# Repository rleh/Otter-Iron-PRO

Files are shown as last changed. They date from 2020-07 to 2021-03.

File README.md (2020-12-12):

# Otter-Iron-PRO

USB-PD soldering station for JBC C245 handles based on the [Otter-Iron](https://github.com/Jan--Henrik/Otter-Iron). More coming soon :)

 - v1.0 tested, works but not great
 - v1.1 untested, wont be tested
 - v2.0 tested, works great! (update: It seems to draw too much current, needs fix)

## Firmware

 - Requests and configures for USB-PD profile of 30 W or 80 W (allows variable).
 - Current limit automatically set based on PD profile available.
 - Profiles can be changed in firmware and enumerated profile will show at start up.
 - Prevents MOSFET driving if no/incompatiable USB-PD profile is advertised; allows setup/flashing with standard USB port.




## v1.0





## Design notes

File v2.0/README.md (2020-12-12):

[https://twitter.com/JanHenrikH/status/1255966040703541251](https://twitter.com/JanHenrikH/status/1255966040703541251)

[BOM](https://github.com/jeanthom/Otter-Iron-PRO-BOM)




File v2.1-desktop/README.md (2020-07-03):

# Otter-Iron-PRO v2.1-desktop

is variant of the _Otter-Iron-PRO v2.0_ designed for desktop-use.

Additional to/instead of USB-PD is can be supplied from any lab power supply with ?? to ?? V.
A cheap switch-mode mains power supply works as well, a stackable enclosure for a  _Meanwell RPS-???_ will be designed in the future.

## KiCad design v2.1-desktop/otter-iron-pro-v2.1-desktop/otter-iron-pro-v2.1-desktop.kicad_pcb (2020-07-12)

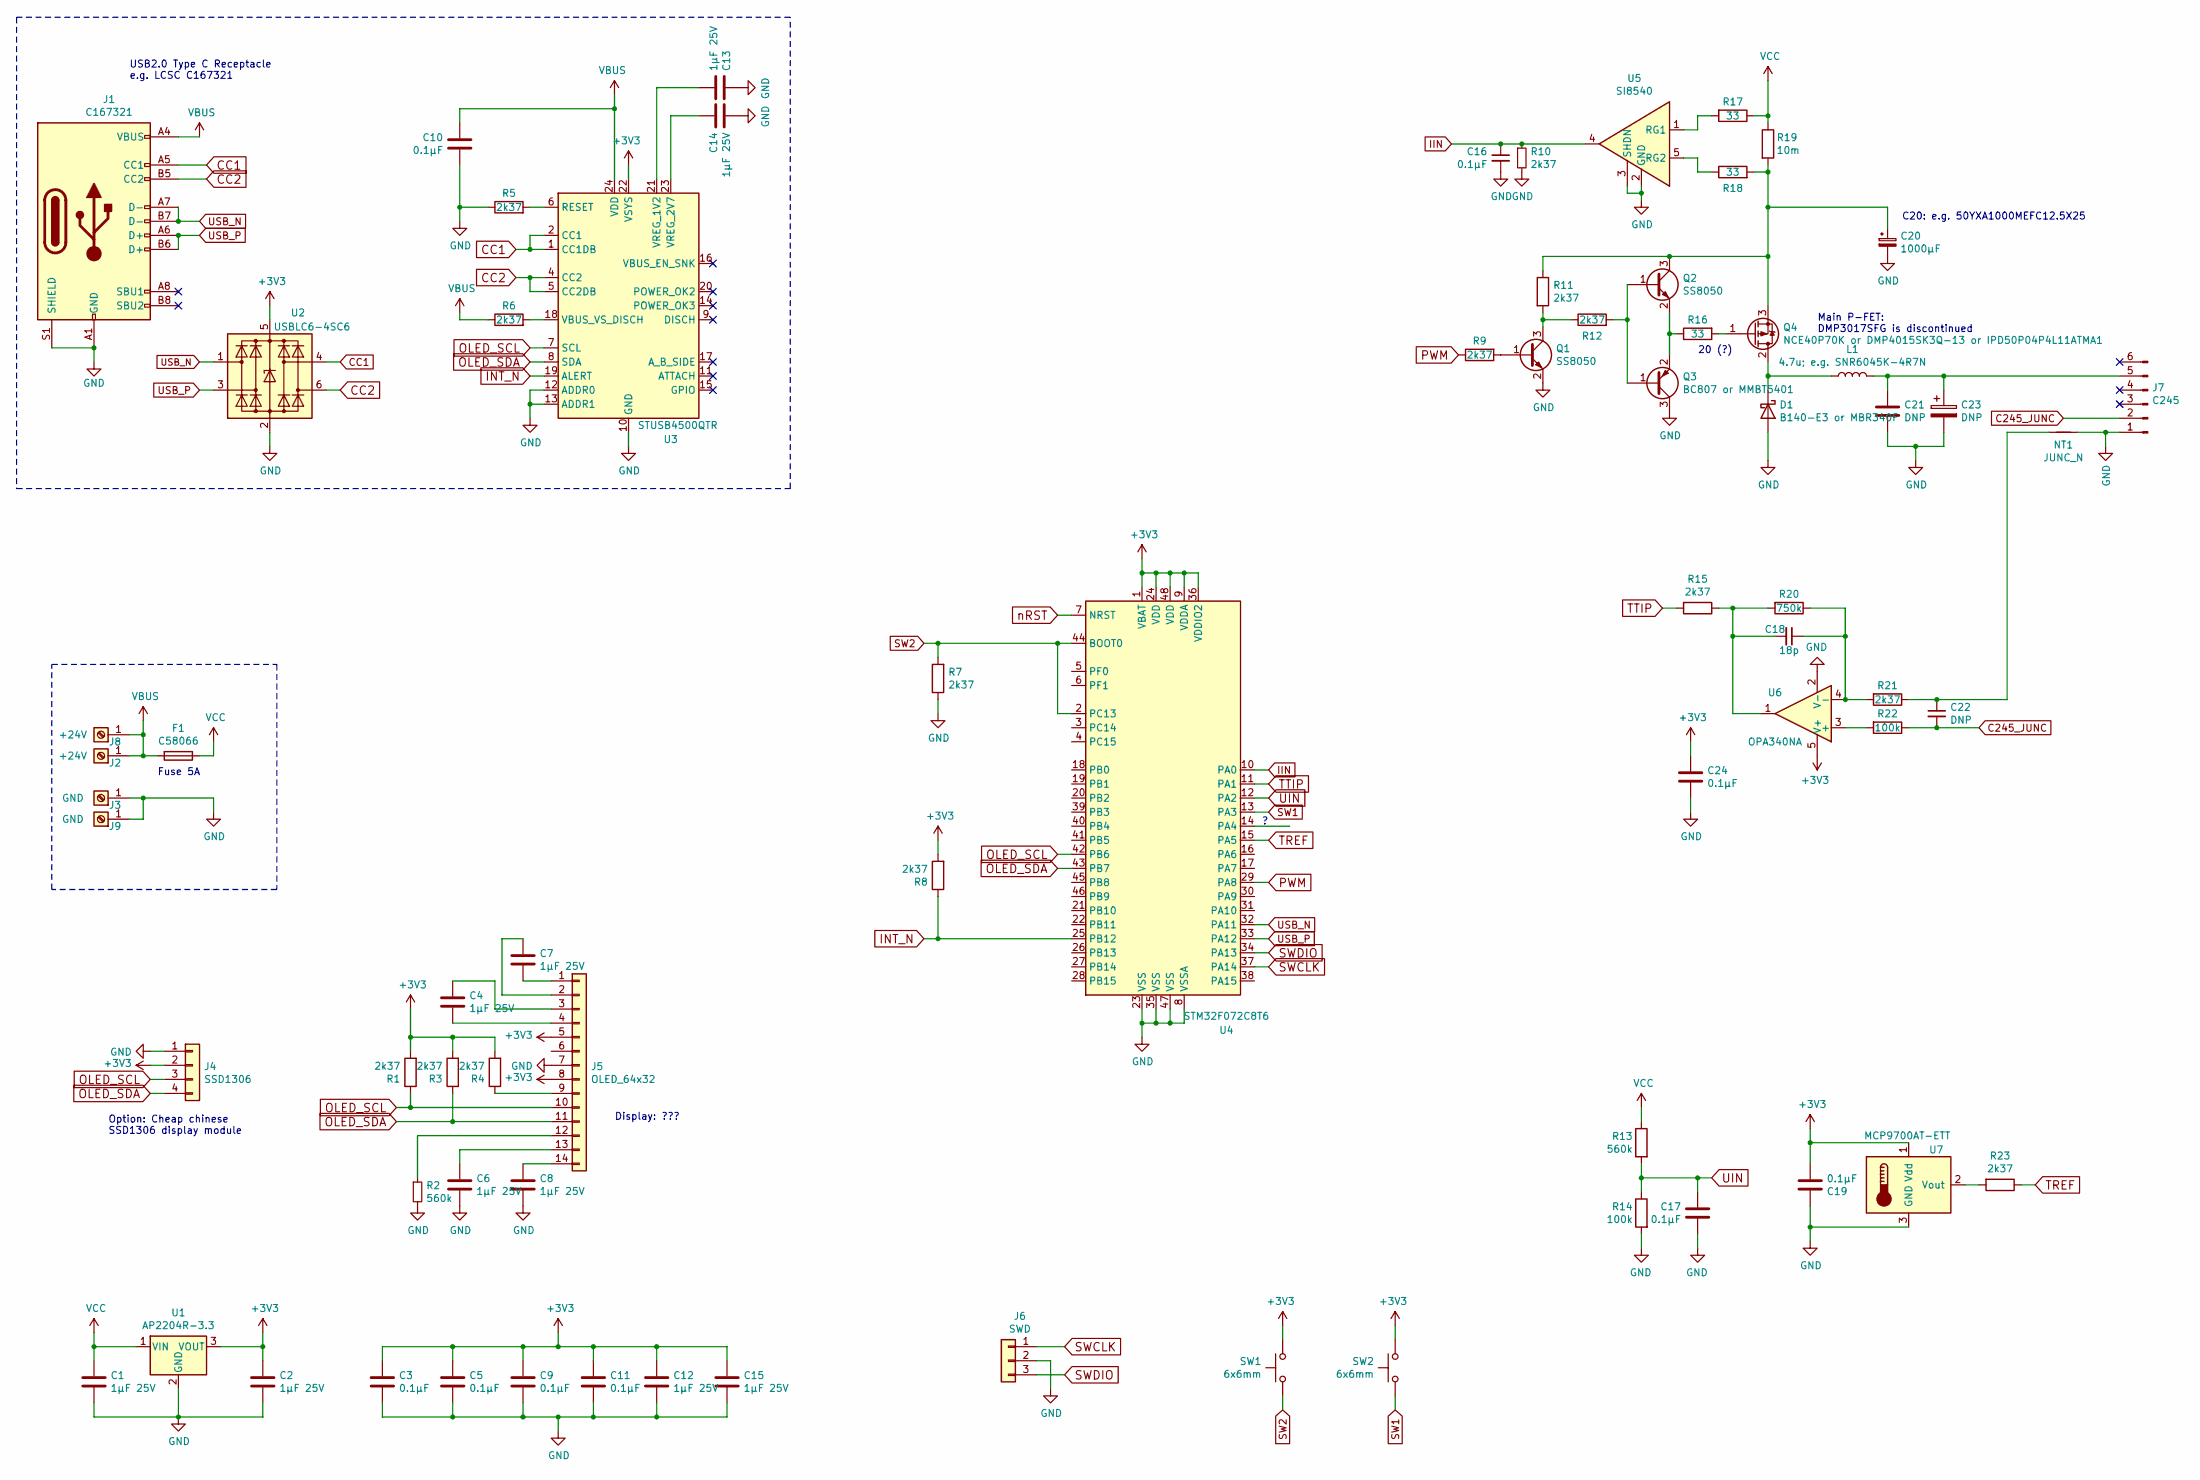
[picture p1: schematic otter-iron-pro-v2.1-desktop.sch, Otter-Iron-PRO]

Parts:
C1, C2, C4, C6, C7, C8, C12, C13, C14, C15: 1μF 25V; C_0603_1608Metric; LCSC C115388
C3, C5, C9, C10, C11, C16, C17, C19, C24: 0.1μF; C_0603_1608Metric; LCSC C30926
C18: 18p; C_0603_1608Metric; LCSC C126551
C20: 1000µF; CP_Radial_D12.5mm_P5.00mm; LCSC C178713
C21, C22: DNP; C_0603_1608Metric
C23: DNP; CP_Radial_D8.0mm_P3.50mm
D1: B140-E3 or MBR340F; D_SOD-123F; LCSC C475721
F1: C58066; Fuseholder_Cylinder-5x20mm_Stelvio-Kontek_PTF78_Horizontal_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; LCSC C58066
J1: C167321; USB_C_Receptacle_Palconn_UTC16-G; LCSC C167321
J2: +24V; Test_Jack_4mm
J3: GND; Test_Jack_4mm
J4: SSD1306; PinHeader_1x04_P2.54mm_Vertical
J5: OLED_64x32; OLED_SSD1306_14pin
J6: SWD; Molex_KK-254_AE-6410-03A_1x03_P2.54mm_Vertical
J7: C245; RPC1-12RB-6P(71)
J8: +24V; Banana_Jack_1Pin
J9: GND; Banana_Jack_1Pin
L1: 4.7u; e.g. SNR6045K-4R7N; L_Taiyo-Yuden_NR-60xx; LCSC C326336
NT1: JUNC_N; NetTie-2_SMD_Pad0.5mm
Q1, Q2: SS8050; SOT-23; LCSC C2150
Q3: BC807 or MMBT5401; SOT-23; LCSC C8326
Q4: NCE40P70K or DMP4015SK3Q-13 or IPD50P04P4L11ATMA1; TO-252-2; LCSC C130101
R1, R3, R4, R5, R6, R7, R8, R9, R10, R11, R12, R15, R21, R23: 2k37; R_0603_1608Metric; LCSC C25964
R2, R13: 560k; R_0603_1608Metric; LCSC C23203
R14, R22: 100k; R_0603_1608Metric; LCSC C15458
R16, R17, R18: 33; R_0603_1608Metric; LCSC C23140
R19: 10m; R_1206_3216Metric; LCSC C104920
R20: 750k; R_0603_1608Metric; LCSC C26005
SW1, SW2: 6x6mm; SW_PUSH_6mm_H13mm; LCSC C493026
U1: AP2204R-3.3; SOT-89-3; LCSC C156303
U2: USBLC6-4SC6; SOT-23-6; LCSC C111212
U3: STUSB4500QTR; QFN-24-1EP_4x4mm_P0.5mm_EP2.7x2.7mm; LCSC C506650
U4: STM32F072C8T6; LQFP-48_7x7mm_P0.5mm; LCSC C80488
U5: SI8540; SOT-23-5
U6: OPA340NA; SOT-23-5; LCSC C73479
U7: MCP9700AT-ETT; SOT-23; LCSC C127949

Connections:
+3V3: C2.1, C3.1, C5.1, C9.1, C11.1, C12.1, C15.1, C19.1, C24.1, J4.2, J5.5, J5.8, R1.2, R3.2, R4.2, R8.2, SW1.1, SW2.1, U1.3 (VOUT), U2.5 (VBUS), U3.22 (VSYS), U4.1 (VBAT), U4.9 (VDDA), U4.24 (VDD), U4.36 (VDDIO2), U4.48 (VDD), U6.5 (V+), U7.1 (Vdd)
C245_JUNC: C22.2, J7.2, R22.1
CC1: J1.A5 (CC1), U2.4 (I/O3), U3.1 (CC1DB), U3.2 (CC1)
CC2: J1.B5 (CC2), U2.6 (I/O4), U3.4 (CC2), U3.5 (CC2DB)
GND: C1.2, C2.2, C3.2, C5.2, C6.2, C8.2, C9.2, C10.2, C11.2, C12.2, C13.1, C14.2, C15.2, C16.2, C17.2, C19.2, C20.2, C21.2, C23.2, C24.2, D1.2 (A), J1.A1 (GND), J1.A12 (GND), J1.B1 (GND), J1.B12 (GND), J1.S1 (SHIELD), J3.1, J4.1, J5.7, J6.2, J7.1, J9.1, NT1.2, Q1.2 (E), Q3.3 (C), R2.2, R5.1, R7.1, R10.2, R14.2, U1.2 (GND), U2.2 (GND), U3.10 (GND), U3.12 (ADDR0), U3.13 (ADDR1), U3.25 (GND), U4.8 (VSSA), U4.23 (VSS), U4.35 (VSS), U4.47 (VSS), U5.2 (GND), U5.3 (SHDN), U6.2 (V-), U7.3 (GND)
IIN: C16.1, R10.1, U4.10 (PA0), U5.4
INT_N: R8.1, U3.19 (ALERT), U4.25 (PB12)
unnamed: C4.1, J5.3
unnamed: C4.2, J5.4
unnamed: C6.1, J5.13
unnamed: C7.1, J5.2
unnamed: C7.2, J5.1
unnamed: C8.1, J5.14
unnamed: C13.2, U3.21 (VREG_1V2)
unnamed: C14.1, U3.23 (VREG_2V7)
unnamed: C18.1, R20.1, R21.2, U6.4 (-)
unnamed: C18.2, R15.1, R20.2, U6.1
unnamed: C20.1, Q2.3 (C), Q4.3 (S), R11.1, R18.2, R19.2
unnamed: C21.1, C23.1, J7.5, L1.2
unnamed: C22.1, NT1.1, R21.1
unnamed: D1.1 (K), L1.1, Q4.2 (D)
unnamed: J5.9, R4.1
unnamed: J5.12, R2.1
unnamed: Q1.1 (B), R9.2
unnamed: Q1.3 (C), R11.2, R12.1
unnamed: Q2.1 (B), Q3.1 (B), R12.2
unnamed: Q2.2 (E), Q3.2 (E), R16.1
unnamed: Q4.1 (G), R16.2
unnamed: R5.2, U3.6 (RESET)
unnamed: R6.2, U3.18 (VBUS_VS_DISCH)
unnamed: R17.2, U5.1 (RG1)
unnamed: R18.1, U5.5 (RG2)
unnamed: R22.2, U6.3 (+)
unnamed: R23.2, U7.2 (Vout)
OLED_SCL: J4.3, J5.10, R1.1, U3.7 (SCL), U4.42 (PB6)
OLED_SDA: J4.4, J5.11, R3.1, U3.8 (SDA), U4.43 (PB7)
PWM: R9.1, U4.29 (PA8)
SW1: SW2.2, U4.13 (PA3)
SW2: R7.2, SW1.2, U4.2 (PC13), U4.44 (BOOT0)
SWCLK: J6.1, U4.37 (PA14)
SWDIO: J6.3, U4.34 (PA13)
TREF: R23.1, U4.15 (PA5)
TTIP: R15.2, U4.11 (PA1)
UIN: C17.1, R13.2, R14.1, U4.12 (PA2)
USB_N: J1.A7 (D-), J1.B7 (D-), U2.1 (I/O1), U4.32 (PA11)
USB_P: J1.A6 (D+), J1.B6 (D+), U2.3 (I/O2), U4.33 (PA12)
VBUS: C10.1, F1.2, J1.A4 (VBUS), J1.A9 (VBUS), J1.B4 (VBUS), J1.B9 (VBUS), J2.1, J8.1, R6.1, U3.24 (VDD)
VCC: C1.1, F1.1, R13.1, R17.1, R19.1, U1.1 (VIN)

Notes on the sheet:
20 (?)
Option: Cheap chinese SSD1306 display module
Display: ???
Fuse 5A
USB2.0 Type C Receptacle e.g. LCSC C167321
Main P-FET: DMP3017SFG is discontinued
C20: e.g. 50YXA1000MEFC12.5X25

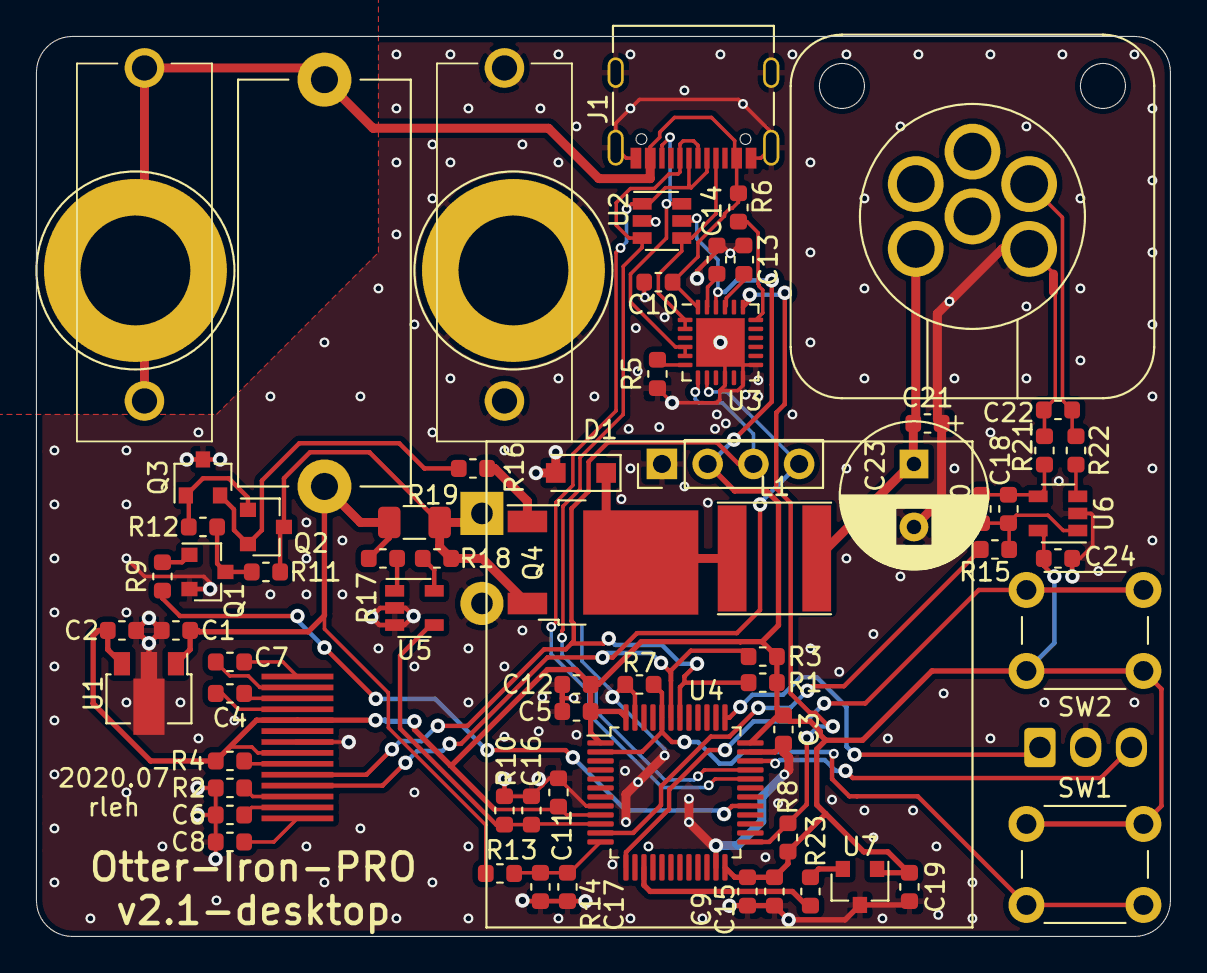
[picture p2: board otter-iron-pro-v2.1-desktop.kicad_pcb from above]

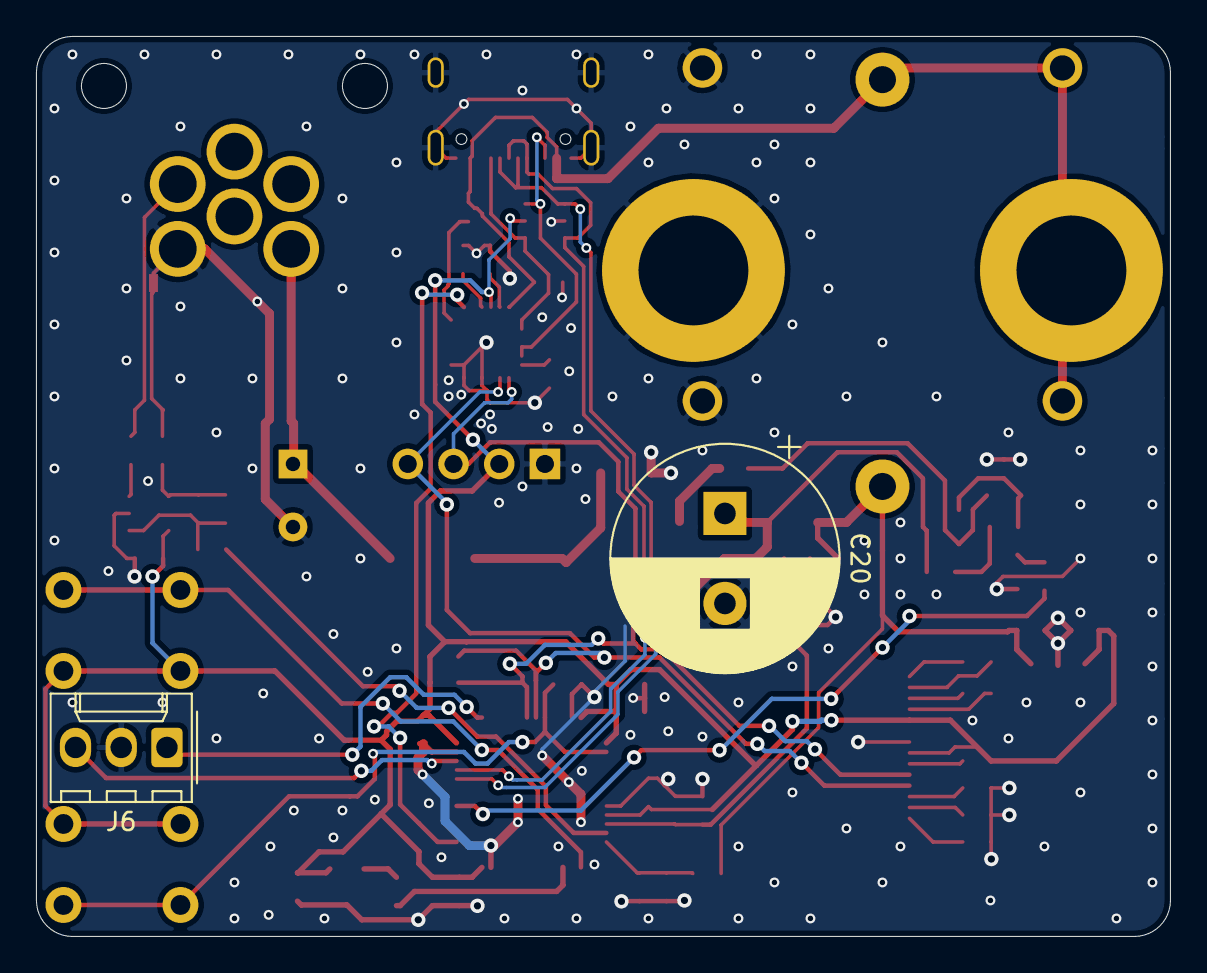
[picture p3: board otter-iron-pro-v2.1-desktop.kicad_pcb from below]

Board: 2 copper layers, 63.0 x 50.0 mm, 73 parts (2 on the bottom side), 48 nets.

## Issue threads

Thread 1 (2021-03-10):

[v2.1-desktop] Todos for PCB rev2

rleh, 2021-03-10:
- I2C für Display und USB-Chip separat (sind eh genügend Pins frei)
- ggf. auf STM32 mit integriertem STUSB4500 wechseln (z.B. STM32G071RB)
- Elkos entfernen (stattdessen MLCC und höhere Schaltfrequenz)
- ggf. besserer/einfacherer Gatetreiber
- Protection-Diode am USB-Port
- Mounting holes für Display
- ...?

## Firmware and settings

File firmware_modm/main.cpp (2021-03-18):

/* Copyright (c) 2017, Raphael Lehmann
 * All Rights Reserved.
 *
 * The file is part of the reflow-oven-modm project and is released under
 * the GPLv3 license.
 * See the file `LICENSE` for the full license governing this code.
 * ------------------------------------------------------------------------- */

#include <modm/math/filter/pid.hpp>
#include <modm/io/iostream.hpp>
#include <modm/processing.hpp>
#include <modm/processing/timer.hpp>
#include <modm/processing/protothread.hpp>
#include <modm/debug/logger.hpp>

#include <array>
#include <chrono>

#include <tusb.h>

#include "hardware.hpp"

#include <modm/driver/usb/stusb4500.hpp>

// modm::IODeviceWrapper<modm::platform::UsbUart0, modm::IOBuffer::DiscardIfFull> loggerDevice;
// modm::log::Logger modm::log::debug(loggerDevice);
// modm::log::Logger modm::log::info(loggerDevice);
// modm::log::Logger modm::log::warning(loggerDevice);
// modm::log::Logger modm::log::error(loggerDevice);

//modm::IODeviceWrapper< Usart1, modm::IOBuffer::BlockIfFull > loggerDevice;
// Set all four logger streams to use the UART
// modm::log::Logger modm::log::debug(loggerDevice);
// modm::log::Logger modm::log::info(loggerDevice);
// modm::log::Logger modm::log::warning(loggerDevice);
// modm::log::Logger modm::log::error(loggerDevice);

using namespace std::literals::chrono_literals;

using namespace modm::literals;

#define UTILS_LP_FAST(value, sample, filter_constant)	(value -= (filter_constant) * ((value) - (sample)))

modm::Pid<float, 1> pid;

modm::Stusb4500<Iron::Display::MyI2cMaster> usb{};

class AdcThread : public modm::pt::Protothread
{
public:
    AdcThread() : adcTimer(1ms) {
    }

    bool update() {
        PT_BEGIN();
        while(1) {
            PT_WAIT_UNTIL(adcTimer.execute());
			lastDuty = Iron::Pwm::getDuty();
			Iron::Pwm::disable();
			modm::delay(50us);
            r = Iron::AnalogReadings::readAll();
			Iron::Pwm::setDuty(lastDuty);
			r.tTip -= r.tRef;
			r.tTip += tRefLp;
			UTILS_LP_FAST(iInLp, r.iIn, 0.01);
			UTILS_LP_FAST(tTipLp, r.tTip, 0.01);
			UTILS_LP_FAST(tRefLp, r.tRef, 0.01);
            PT_YIELD();
        }
        PT_END();
    }
	
	float getIInLp() const { return iInLp; };
	float getUIn() const { return r.uIn; };
	float getTTipLp() const { return tTipLp; };
	float getTRef() const { return tRefLp; };

	float getTipResistance() const {
		return 2.6f;
	}

private:
    modm::ShortPrecisePeriodicTimer adcTimer;
	Iron::AnalogReadings::Readings r; 
	float tTipLp; // low-pass filtered tip temperature in [°C]
	float iInLp; // low-pass filtered input current [A]
	float tRefLp;  // low-pass filtered reference temperature in [°C]
	float lastDuty;
};
AdcThread adcThread;

class PidThread : public modm::pt::Protothread
{
public:
	PidThread() : pidTimer(10ms), tSetpoint(320.0f)
	{

	}

	bool
	update()
	{
		PT_BEGIN();

		while (1)
		{
			if(true) {
				PT_WAIT_UNTIL(pidTimer.execute());
				tTipLp = adcThread.getTTipLp();
				if( 0.0f <= tTipLp && tTipLp <= 700.0f ) { // FIXME
					pid.update(tSetpoint - tTipLp );
					// 800/2000 since we use PID values from original otter iron firmware
					// duty = std::max<float>(0.0f, pid.getValue())*800.0f/2000.0f;
					dutyLimit = adcThread.getTipResistance() * powerLimit / (adcThread.getUIn()*adcThread.getUIn()); 
					dutyLimit = std::min<float>(dutyLimit, 1.0f);
					duty = std::max<float>(0.0f, pid.getValue())*adcThread.getTipResistance()/ ( adcThread.getUIn()*adcThread.getUIn() );
					duty = std::max<float>(0, std::min<float>(dutyLimit, duty));
					Iron::Pwm::setDuty(duty);
				}
				else {
                    // MODM_LOG_INFO << "Error: Invalid temperature measurement" << modm::endl;
                    // MODM_LOG_INFO << tTipLp << modm::endl;
				}
			}
			else {
				Iron::Pwm::disable();
			}
			PT_YIELD();
		}

		PT_END();
	}

	float tSetpoint;
	float duty;
	float powerLimit; // [W]
private:
	modm::PeriodicTimer pidTimer;
	float tTipLp;
	float dutyLimit;
};
PidThread pidThread;




// UiThread updates the display and reads the
// button states (with debouncing).
class UiThread : public modm::pt::Protothread
{
public:
	UiThread() :
		inputTimer(100ms),
		displayTimer(200ms)
	{
	}

	bool update(){
		PT_BEGIN();
		while (1)
		{
			if(inputTimer.execute()) {
				if ( Iron::Ui::ButtonUp::read() ) {
					pidThread.tSetpoint += 5.f; // [°C]
				}
				if ( Iron::Ui::ButtonDown::read()) {
					pidThread.tSetpoint -= 5.f; // [°C]
				}
			}
			if( displayTimer.execute()) {
				// MODM_LOG_INFO << "Temperatures: tTipLp=";
				// MODM_LOG_INFO << printf("%03.2f", adcThread.getTTipLp());
				// MODM_LOG_INFO << "°C, tSetpoint=";
				// MODM_LOG_INFO << printf("%03.2f", pidThread.tSetpoint);
				// MODM_LOG_INFO << "°C\n";

				Iron::Display::display.clear();
				Iron::Display::display.setCursor(0,0);
				Iron::Display::display.printf("T=%03.2f", adcThread.getTTipLp());
				Iron::Display::display.setCursor(64,0);
				Iron::Display::display.printf("S=%03.2f", pidThread.tSetpoint);
				Iron::Display::display.setCursor(0,32);
				Iron::Display::display.printf("D=%03.2f", pidThread.duty);
				Iron::Display::display.setCursor(64,32);
				Iron::Display::display.printf("R=%03.2f", adcThread.getTRef());
				Iron::Display::display.setCursor(0,48);
				Iron::Display::display.printf("U=%03.2f", adcThread.getUIn());
				Iron::Display::display.setCursor(64,48);
				Iron::Display::display.printf("I=%03.2f", adcThread.getIInLp());
				Iron::Display::display.update();
			}
			
			PT_YIELD();
		}
		PT_END();
	}
private:
	modm::PeriodicTimer inputTimer;
	modm::PeriodicTimer displayTimer;
};
UiThread uiThread;


int main()
{
    modm::delay(500ms);
	Iron::SystemClock::enable();
	modm::platform::SysTickTimer::initialize<Iron::SystemClock>();
	// Iron::usb::initialize();
	// tusb_init();

    // Usart1::connect<GpioA9::Tx>();
	// Usart1::initialize<Board::systemClock,115200_Bd>();
	// MODM_LOG_INFO << "Otter-Iron-PRO-v2.1-Desktop:modm-firmware starting ..." << modm::endl;
	// MODM_LOG_INFO << "Docker build ... \n" <<
	// " Step 1/2 : RUN apt-get update && apt-get install -y otter-iron-firmware \n" <<
 	// " ---> Using cache \n" <<
	// " ---> 946ee47ee05e \n" << 
	// " Step 2/2 : RUN chmod +x /opt/otter-iron-firmware/firmware.elf \n" <<
 	// " ---> Using cache \n" <<
 	// " ---> 2f7d8ceee512 \n" <<
	// " Successfully built 2f7d8ceee512 " << modm::endl;
	// modm::delay(100ms);
	// MODM_LOG_INFO << "VXWorks Initialized ..." << modm::endl;
	// MODM_LOG_INFO << "License Test ... USB License-Key not found ... Falling back to factory default ... Expired" << modm::endl;
	// MODM_LOG_INFO << "Please contact Sales Representative at vx@schulz-krause.de" << modm::endl;
	// modm::delay(100ms);
	// MODM_LOG_INFO << "Waiting for 5G to become available..." << modm::endl;
	// modm::delay(100ms);
	// MODM_LOG_INFO << "Baseband not found..." << modm::endl;
	// MODM_LOG_INFO << "Falling back to Fiber..." << modm::endl;
	// modm::delay(100ms);
	// MODM_LOG_INFO << "Falling back to Fiber..." << modm::endl;
	// modm::delay(100ms);
	// MODM_LOG_INFO << "Connection Successfull" << modm::endl;

	Iron::Display::MyI2cMaster::connect<
		Iron::Display::Scl::Scl, 
		Iron::Display::Sda::Sda>();
	Iron::Display::MyI2cMaster::initialize<Iron::SystemClock, 400_kHz>();


	Iron::Pwm::initialize();
	Iron::AnalogReadings::initialize();
	Iron::Ui::initialize();


	RF_CALL_BLOCKING(usb.configurePdo(1, 5000, 500));
	RF_CALL_BLOCKING(usb.configurePdo(2, 20000, 1500));
	RF_CALL_BLOCKING(usb.configurePdo(3, 20000, 4000));

	// pdo number expected {1,2,3}
	RF_CALL_BLOCKING(usb.setValidPdo(3));

	// check results
	modm::delay(200ms);
	modm::stusb4500::RdoRegStatusData status = RF_CALL_BLOCKING(usb.getRdoRegStatus());
	auto r = Iron::AnalogReadings::readAll();

	Iron::Display::initialize();
	Iron::Display::display.clear();
	// Iron::Display::display.setCursor(0,0);
	// Iron::Display::display.printf("Docker build");
	
	Iron::Display::display.setCursor(0,0);
	Iron::Display::display.printf("USB PD... ");
	Iron::Display::display.update();

	Iron::Display::display.setCursor(60,0);
	Iron::Display::display.printf("OP %1d", status.ObjectPos);
	Iron::Display::display.setCursor(0,16);
	Iron::Display::display.printf("UIn %03.2f V", r.uIn);
	Iron::Display::display.setCursor(0,32);
	Iron::Display::display.printf("Max %04ld mA", status.MaxCurrent);
	Iron::Display::display.setCursor(0,48);
	pidThread.powerLimit = status.MaxCurrent*r.uIn/1000; // [W]
	Iron::Display::display.printf("Pwr %03.2f W", pidThread.powerLimit);
	Iron::Display::display.update();

	modm::delay(5s);

	if ( status.MaxCurrent == 0 ){
		uint32_t maxManualCurrent = 0; // [mA]
		const uint16_t step = 500; //[mA]
		auto updateDisp = [&maxManualCurrent](){
				Iron::Display::display.clear();
				Iron::Display::display.setCursor(0,0);
				Iron::Display::display.printf("No USB PD");
				Iron::Display::display.setCursor(0,16);
				Iron::Display::display.printf("Select current!");
				Iron::Display::display.setCursor(0,48);
				Iron::Display::display.printf("Ack with +&-");
				Iron::Display::display.setCursor(0,32);
				Iron::Display::display.printf("Max %04ld mA", maxManualCurrent);
				Iron::Display::display.update();
			};
		updateDisp();
		modm::delay(200ms);
		while( true ) {
			if ( Iron::Ui::ButtonUp::read() ) {
				modm::delay(200ms);
				if ( Iron::Ui::ButtonUp::read() && Iron::Ui::ButtonDown::read() ) break;
				else maxManualCurrent += step;
				if ( maxManualCurrent > 10000 ) maxManualCurrent = 10000; 
				updateDisp();
			}
			else if ( Iron::Ui::ButtonDown::read() ) {
				modm::delay(200ms);
				if ( Iron::Ui::ButtonUp::read() && Iron::Ui::ButtonDown::read() ) break;
				else {
					if ( maxManualCurrent >= step ) maxManualCurrent-=step;
				}
				updateDisp();		 
			} 

		}
		Iron::Display::display.clear();
		Iron::Display::display.setCursor(0,16);
		Iron::Display::display.printf("Max %04ld mA", maxManualCurrent);
		Iron::Display::display.setCursor(0,32);
		pidThread.powerLimit = maxManualCurrent*r.uIn/1000; // [W]
		Iron::Display::display.printf("Pwr %03.2f W", pidThread.powerLimit);
		Iron::Display::display.update();
		modm::delay(5s);
	}



	Iron::Display::MyI2cMaster::initialize<Iron::SystemClock, 1200_kHz>();
	/*
	* use PID with [K] temperatures
	*/
	pid.setParameter(modm::Pid<float, 1>::Parameter( 
		2.0f,	// Kp
		4.0f,	// Ki
		0.0f, 		// Kd
		10.0f,  	// err_I limit
		Iron::Pwm::Overflow)); // output limit

	// MODM_LOG_DEBUG << "PWM Timer Overflow: " << Iron::Pwm::Overflow << modm::endl;

	//uint8_t counter = 0; 

	while (1)
	{
        adcThread.update();
		pidThread.update();
		uiThread.update();

		// tud_task();

		// MODM_LOG_INFO << "Loop" << modm::endl;
	}
	return 0;
}

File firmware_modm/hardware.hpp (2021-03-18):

/* Copyright (c) 2017, Raphael Lehmann
 * All Rights Reserved.
 *
 * The file is part of the reflow-oven-modm project and is released under
 * the GPLv3 license.
 * See the file `LICENSE` for the full license governing this code.
 * ------------------------------------------------------------------------- */
#ifndef HARDWARE_HPP
#define HARDWARE_HPP

#include <modm/driver/display/ssd1306.hpp>
#include <modm/platform.hpp>
#include <modm/architecture/interface/clock.hpp>
#define UTILS_LP_FAST(value, sample, filter_constant)	(value -= (filter_constant) * ((value) - (sample)))


namespace Iron
{

using namespace modm::literals;
using namespace modm::platform;

// COPIED FROM modm example for STM32F072_Discovery 
/// STM32F072 running at 48MHz generated from the internal 48MHz clock
// TODO: enable once clock driver is implemented
//using SystemClock = SystemClock<InternalClock<48_MHz>, 48_MHz>;

struct SystemClock
{
	static constexpr int Frequency = 48_MHz;
	static constexpr uint32_t Ahb = Frequency;
	static constexpr uint32_t Apb = Frequency;

	static constexpr uint32_t Adc   = Apb;
	static constexpr uint32_t Can   = Apb;

	static constexpr uint32_t Spi1   = Apb;
	static constexpr uint32_t Spi2   = Apb;

	static constexpr uint32_t Usart1 = Apb;
	static constexpr uint32_t Usart2 = Apb;
	static constexpr uint32_t Usart3 = Apb;
	static constexpr uint32_t Usart4 = Apb;

	static constexpr uint32_t I2c1   = Apb;
	static constexpr uint32_t I2c2   = Apb;

	static constexpr uint32_t Timer1  = Apb;
	static constexpr uint32_t Timer2  = Apb;
	static constexpr uint32_t Timer3  = Apb;
	static constexpr uint32_t Timer6  = Apb;
	static constexpr uint32_t Timer7  = Apb;
	static constexpr uint32_t Timer14 = Apb;
	static constexpr uint32_t Timer15 = Apb;
	static constexpr uint32_t Timer16 = Apb;
	static constexpr uint32_t Timer17 = Apb;

	static constexpr uint32_t Usb = Frequency;

	static bool inline
	enable()
	{
		// Enable the interal 48MHz clock
		Rcc::enableInternalClockMHz48();
		// set flash latency for 48MHz
		Rcc::setFlashLatency<Frequency>();
		// Switch to the 48MHz clock
		Rcc::enableSystemClock(Rcc::SystemClockSource::InternalClockMHz48);
		// update frequencies for busy-wait delay functions
		Rcc::updateCoreFrequency<Frequency>();

		return true;
	}
};

namespace usb
{
    using Dm = GpioA11;
    using Dp = GpioA12;

    using Device = UsbFs;

    inline void
    initialize()
    {
        Device::initialize<SystemClock>();
        Device::connect<Dm::Dm, Dp::Dp>();
    }
}


namespace Ui {
	using ButtonUp = GpioA3; // SW2 on silk, has external pulldown
	using ButtonDown = GpioC13; // SW1 on silk

	inline void
	initialize()
	{
		ButtonUp::setInput(ButtonUp::InputType::PullDown);
		ButtonDown::setInput(ButtonDown::InputType::PullDown);
	}
}


namespace Display {
	using Sda = GpioB7;
	using Scl = GpioB6;
	using MyI2cMaster = I2cMaster1;
	modm::Ssd1306<MyI2cMaster> display;

	inline void
	initialize()
	{

        display.initializeBlocking();
		display.setFont(modm::font::Assertion);
		display.setCursor(0,16);
		display << "Otter Iron v2.1";
		display.update();
	}
}

namespace Pwm {
	using Timer = Timer1;
	using Pin = GpioOutputA8;
	static uint16_t Overflow = 2400;

	inline void
	initialize()
	{
	    Pin::setOutput();
		Timer::connect<Pin::Ch1>();
		Timer::enable();
		Timer::setMode(Timer::Mode::UpCounter);
		// Pwm frequency: 20kHz
		Timer::setPrescaler(1); // 48 * 1000 * 1000 / 10000 / 2400 = 1
		Timer::setOverflow(Overflow);
		Timer::configureOutputChannel(1, Timer::OutputCompareMode::Pwm, 0);
		Timer::applyAndReset();
		Timer::start();
        Timer::enableOutput();
	}

	inline void
	set(uint16_t value)
	{
		Timer::setCompareValue(1, value);
		
	}

	inline uint16_t
	get()
	{
		return Timer::getCompareValue(1);
		
	}


    // Use duty [0...1]
    inline void 
    setDuty(float duty) {
        duty = std::max<float>(0, std::min<float>(1.0f, duty));
        set(duty * Overflow);
    }

	inline float
	getDuty() {
		return float(get()) / float(Overflow);
	}

	inline void
	disable()
	{
		set(0);
	}
}
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

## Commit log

2020-07-03 Create variant v2.1-desktop
    [otter-iron-pro-v2.1-desktop.kicad_pcb, otter-iron-pro-v2.1-desktop.sch, v2-bottom.sch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]
2020-07-03 Import v2.0 schematics
    [v2-bottom.sch, v2-c245.sch, v2-top.sch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]
2020-07-03 Consolidate schematics into a single sheet
    [otter-iron-pro-v2.1-desktop.sch, v2-bottom.sch, v2-c245.sch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]
2020-07-04 Finish schematic, start layouting...
    [otter-iron-pro-v2.1-desktop.kicad_pcb, otter-iron-pro-v2.1-desktop.sch]
2020-07-06 Layout draft
    [otter-iron-pro-v2.1-desktop.kicad_pcb, otter-iron-pro-v2.1-desktop.sch]
2020-07-12 Finish layout
    [otter-iron-pro-v2.1-desktop.kicad_pcb]
2020-07-12 Silkscreen and GND area fill
    [otter-iron-pro-v2.1-desktop.kicad_pcb]
2020-07-12 Export gerbers; Add LCSC part numbers
    [otter-iron-pro-v2.1-desktop.kicad_pcb, otter-iron-pro-v2.1-desktop.sch]
2020-12-21 initial commit on new modm based firmware: - display works, but update rate is slow at 400kHz, should try increasing in future - buttons adjust temp setpoint, but are mirrord - ADC samples incorrect 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
    [hardware.hpp, main.cpp]
2021-01-10 Changed controller to outputting power [W] instead of duty cycle, limiting total output power, disabling output pwm before sampling ADC
2021-03-04 bug fixed in i2c
    [main.cpp]
2021-03-09 functional USB-PD (kind of... we dont understand how, but it works - and we didnt touch a single page of USB standard)...
    some kind of menue for selecting input current limit if no USB-PD
    general bug fixes and useability improvements
    [hardware.hpp, main.cpp]
2021-03-09 Use upstreamed modm::Stusb4500 driver
